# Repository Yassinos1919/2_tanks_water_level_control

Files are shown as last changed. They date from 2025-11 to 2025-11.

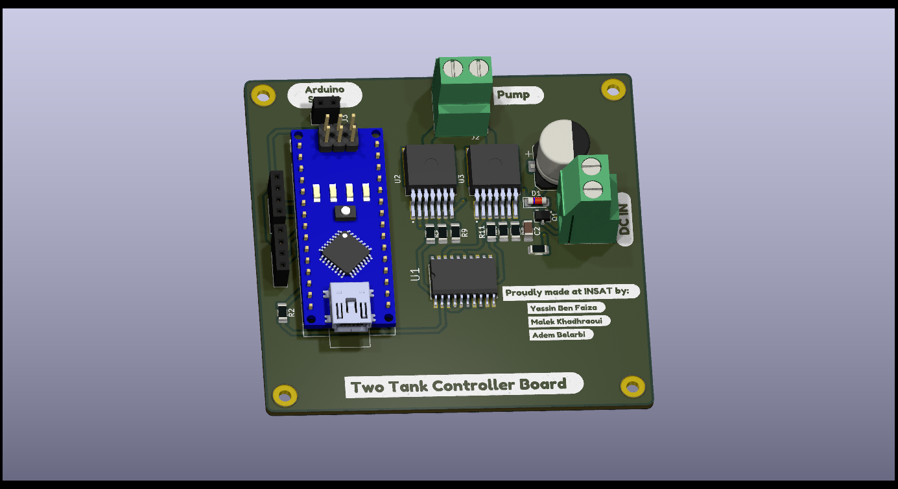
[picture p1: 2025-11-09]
pcb/projetCAO2.png

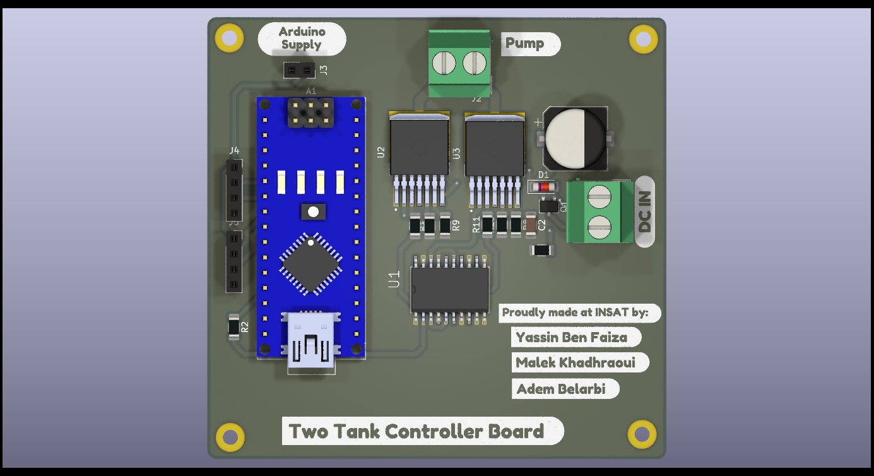
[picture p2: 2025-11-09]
pcb/projetCAO.png

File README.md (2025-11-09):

# Two-Tank Liquid Level Controller 🎛️💧

An automated control system that maintains constant liquid levels in a coupled two-tank setup using PID control, Arduino, and LabVIEW.





## 📋 Project Overview

This project implements an industrial-grade liquid level control system for a coupled two-tank configuration. The system uses PID control to maintain a desired water level in the second tank, demonstrating fundamental control theory principles with practical hardware implementation.

**Key Features:**
- ✅ Real-time PID level control
- ✅ Custom PCB design
- ✅ LabVIEW monitoring interface
- ✅ Ultrasonic sensor integration
- ✅ PWM pump control
- ✅ Remote parameter tuning

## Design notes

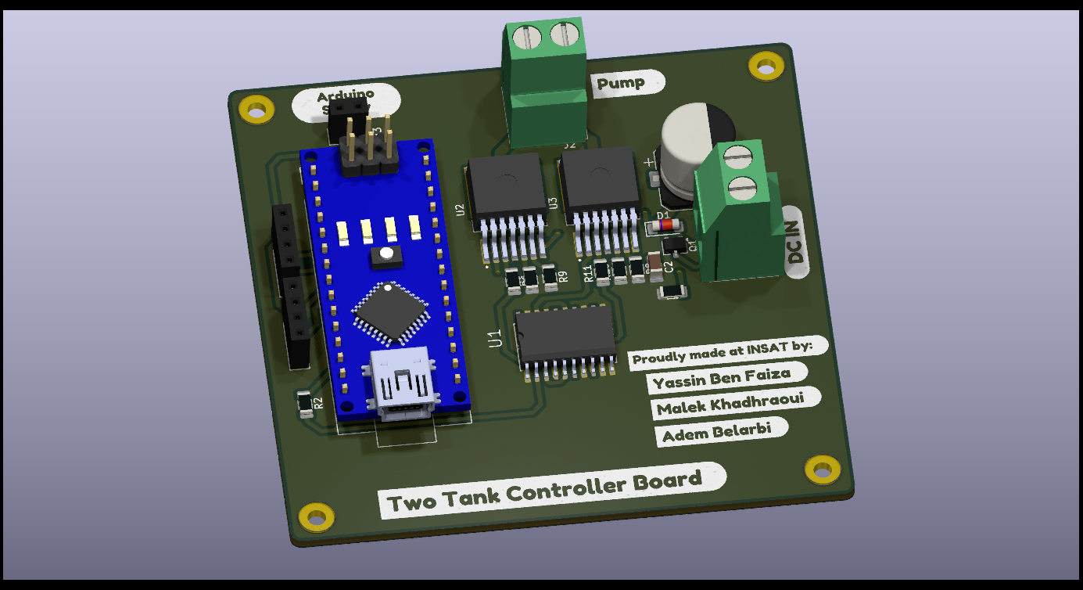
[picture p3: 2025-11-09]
pcb/projetCAO3.png

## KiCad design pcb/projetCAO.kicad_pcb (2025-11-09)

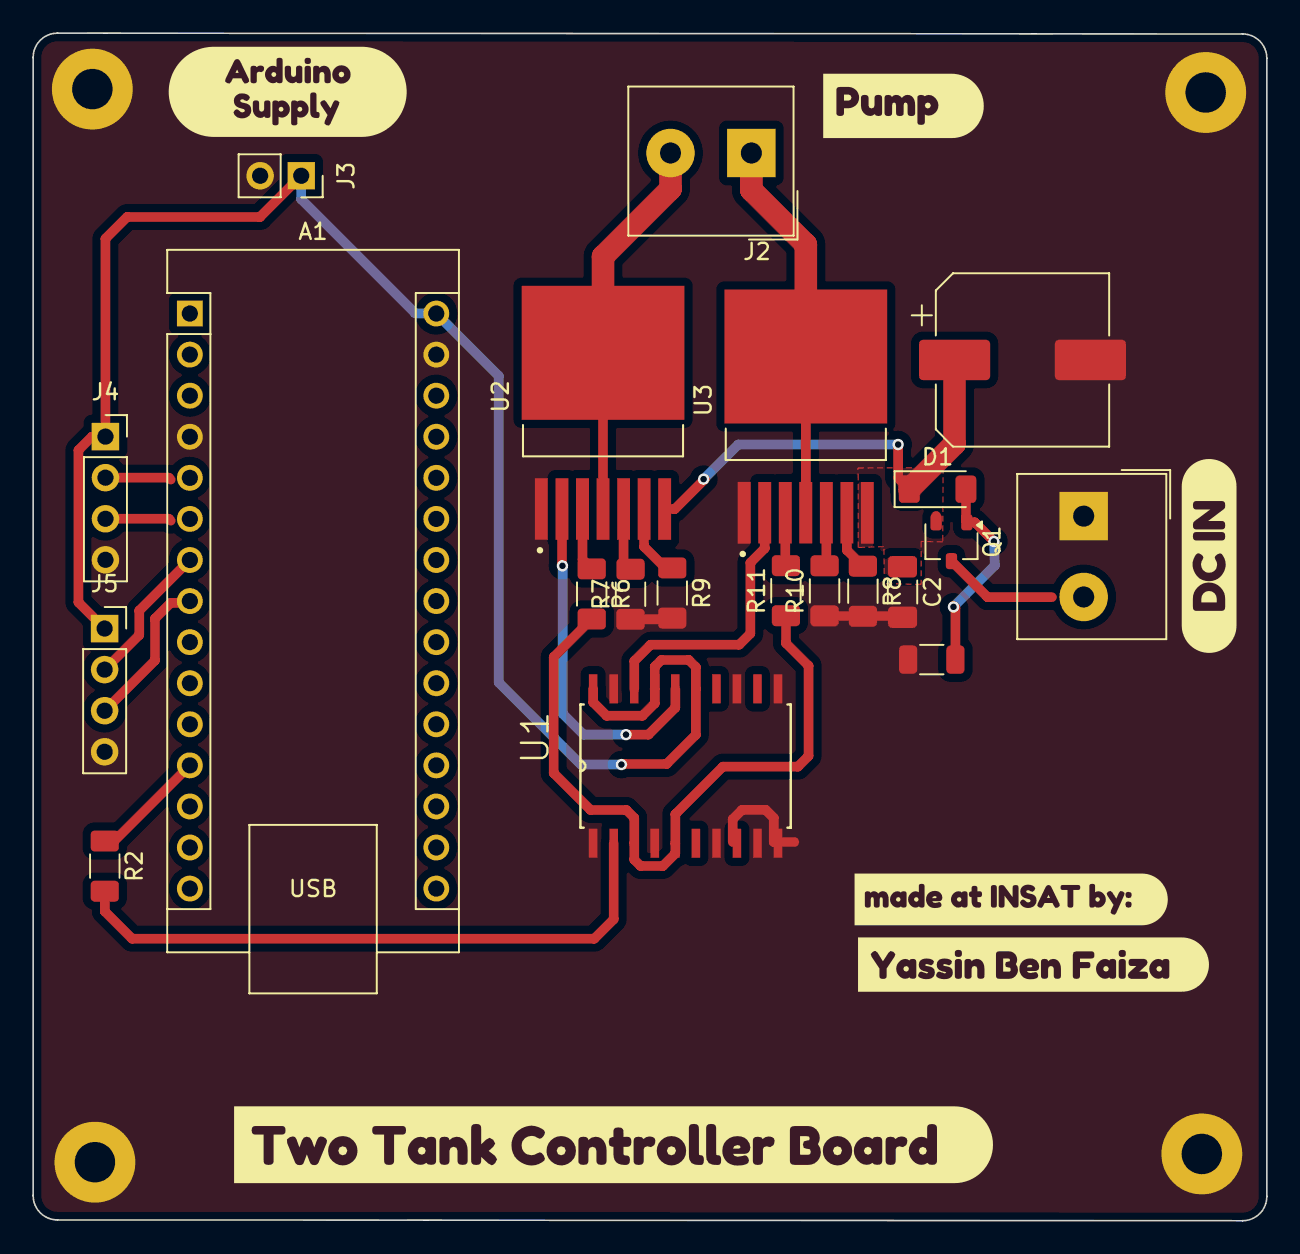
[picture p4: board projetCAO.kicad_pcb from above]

Board: 2 copper layers, 76.3 x 73.4 mm, 31 parts (0 on the bottom side), 22 nets.

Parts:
A1: Arduino_Nano_v3.x; Arduino_Nano
C1: 470u; CP_Elec_10x10.5
C2: 100n; C_1206_3216Metric_Pad1.33x1.80mm_HandSolder
D1: BZV55B10; D_MiniMELF
H1, H2, H3, H4: MountingHole_Pad; MountingHole_2.5mm_Pad
J1: 12V input; Altech_AK100_1x02_P5.00mm
J2: OUT; Altech_AK100_1x02_P5.00mm
J3: Alimentation; PinSocket_1x02_P2.54mm_Vertical
J4: Ultrasonic1; PinSocket_1x04_P2.54mm_Vertical
J5: Ultrasonic2; PinSocket_1x04_P2.54mm_Vertical
Q1: AO3401A; SOT-23W
R1: 10K; R_1206_3216Metric
R2, R6, R11: 10K; R_1206_3216Metric_Pad1.30x1.75mm_HandSolder
R7, R8, R9, R10: 4.7K; R_1206_3216Metric_Pad1.30x1.75mm_HandSolder
U1: 74HC244; SOIC127P1032X265-20N
U2, U3: BTS7960B; DPAK127P1490X440-8N
kibuzzard-68C5A47A: G***; kibuzzard-68C5A47A
kibuzzard-681AAFCF: G***; kibuzzard-681AAFCF
kibuzzard-681AB00E: G***; kibuzzard-681AB00E
kibuzzard-681AB02C: G***; kibuzzard-681AB02C
kibuzzard-681AC34F: G***; kibuzzard-681AC34F
kibuzzard-67925609: G***; kibuzzard-67925609

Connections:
ECHO1: A1.6 (D3), J4.3
ECHO2: A1.8 (D5), J5.3
EN: R6.2, R11.1, U1.3 (2Y0), U1.5 (2Y1)
GND: A1.4 (GND), A1.29 (GND), C1.2, C2.2, H1.1, H2.1, H3.1, H4.1, J1.1, J3.2, J4.4, J5.4, R1.2, R7.1, R8.2, R9.2, R10.1, U1.1 (1OE), U1.4 (1A1), U1.7 (2Y2), U1.9 (2Y3), U1.10 (GND), U1.11 (2A3), U1.13 (2A2), U1.19 (2OE), U2.1 (GND), U3.1 (GND)
unnamed: D1.2 (A), Q1.1 (G), R1.1
unnamed: J1.2, Q1.3 (D)
unnamed: J2.1, U3.4 (OUT), U3.8 (OUT)
unnamed: J2.2, U2.4 (OUT), U2.8 (OUT)
unnamed: R2.2, U1.2 (1A0)
unnamed: R6.1, U2.3 (INH)
unnamed: R9.1, U2.6 (IS)
unnamed: R7.2, U2.5 (SR)
unnamed: R11.2, U3.3 (INH)
unnamed: R8.1, U3.6 (IS)
unnamed: R10.2, U3.5 (SR)
OUT1: U1.18 (1Y0), U3.2 (IN)
OUT2: U1.16 (1Y1), U2.2 (IN)
RPWM1: A1.12 (D9), R2.1
Supply: C1.1, C2.1, D1.1 (K), Q1.2 (S), U2.7 (VS), U3.7 (VS)
TRIG1: A1.5 (D2), J4.2
TRIG2: A1.7 (D4), J5.2
VCC: A1.30 (VIN), J3.1, J4.1, J5.1, U1.15 (2A1), U1.17 (2A0), U1.20 (VCC)

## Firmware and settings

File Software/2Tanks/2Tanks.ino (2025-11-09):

#include <PID_v1.h>

// Tank heights
const float tankHeight1 = 13.0;
const float tankHeight2 = 15.0;

// Ultrasonic pins
const int trig1 = 2, echo1 = 3; // Tank 1
const int trig2 = 4, echo2 = 5; // Tank 2

// Pump control
const int pumpPWM = 9;

// PID variables
double setpoint = 6;
double input, output;
double Kp = 100, Ki = 1, Kd = 0.1;

// PID setup
PID myPID(&input, &output, &setpoint, Kp, Ki, Kd, DIRECT);

void setup() {
  Serial.begin(115200);

  pinMode(trig1, OUTPUT);
  pinMode(echo1, INPUT);
  pinMode(trig2, OUTPUT);
  pinMode(echo2, INPUT);
  pinMode(pumpPWM, OUTPUT);

  myPID.SetMode(AUTOMATIC);
  myPID.SetOutputLimits(0, 255); // PWM range
}

float getLevel(int trigPin, int echoPin, float tankHeight) {
  digitalWrite(trigPin, LOW);
  delayMicroseconds(2);
  digitalWrite(trigPin, HIGH);
  delayMicroseconds(10);
  digitalWrite(trigPin, LOW);

  long duration = pulseIn(echoPin, HIGH, 30000);
  float distance = duration * 0.034 / 2.0;

  float level = tankHeight - distance;
  if (level < 0) level = 0;
  if (level > tankHeight) level = tankHeight;
  return level;
}

void loop() {
  // Read tank levels
  float tank1Level = getLevel(trig1, echo1, tankHeight1);
  input = getLevel(trig2, echo2, tankHeight2);

  // Compute PID
  myPID.Compute();
  analogWrite(pumpPWM, (int)output);

  // --- Serial Receive Format: "Kp,Ki,Kd,Setpoint\n" ---
  if (Serial.available()) {
    String s = Serial.readStringUntil('\n');
    s.trim(); // Remove trailing newline
    int idx1 = s.indexOf(',');
    int idx2 = s.indexOf(',', idx1 + 1);
    int idx3 = s.indexOf(',', idx2 + 1);

    if (idx1 > 0 && idx2 > idx1 && idx3 > idx2) {
      // Extract values
      Kp = s.substring(0, idx1).toFloat();
      Ki = s.substring(idx1 + 1, idx2).toFloat();
      Kd = s.substring(idx2 + 1, idx3).toFloat();
      setpoint = s.substring(idx3 + 1).toFloat();

      // Update PID tunings
      myPID.SetTunings(Kp, Ki, Kd);
    }
  }

  // --- Send to LabVIEW ---
  Serial.print(tank1Level); Serial.print(",");
  Serial.print(input); Serial.print(",");
  Serial.println(output);

  delay(500);
}

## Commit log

2025-11-09 project added
    [projetCAO.kicad_pcb, projetCAO.kicad_sch]
2025-11-09 Rename Capture d'écran 2025-11-09 123720.png to prototype
